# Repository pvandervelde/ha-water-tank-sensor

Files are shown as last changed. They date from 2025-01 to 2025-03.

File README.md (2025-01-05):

# ha-water-tank-sensor

Stores the code and schematics for the system we use to monitor the level in the water tanks on our
property.

Consists of a IoT device that measures the water level in the tank and sends it to the service
using WIFI. The service extracts the data from the message and sends it to a Grafana stack.

* Schema -> KiCad
* PCB -> KiCad (not done)

## The embedded device

### Hardware

* ESP32-C6 DevKit
* Submerged pressure sensor
* BME280 for temperature and humidity
* Light sensitive diode - To check that the enclosure is still sealed
* Solar panel
* Battery (1.3 Ah)
* ADS1115 - To read the analog values from the pressure sensor
* TSR_1-2450 - To regulate the voltage from the battery to the ESP32. Generating 5V for the devkit
* SDLA12TA - Solar charge module
* EC2-3NU - Relay to turn on/off the sensor
* XL6009E1 - DC-DC converter to generate 24V for the pressure sensor
* BS170 - N-channel MOSFET to turn on/off the relay

### Pin assignments

* ESP32-C6 DevKit
  * 5V - TSR_1-2450
  * 3V3 - BME280, ADS1115, Light sensitive diode
  * GND - BME280, ADS1115, Light sensitive diode
  * SDA - BME280, ADS1115,
  * SCL - BME280, ADS1115,
  * GPIO 10 - SDA (ADS1115, BME280)
  * GPIO 11 - SCL (ADS1115, BME280)
  * GPIO 18 - Boost enable (BS170)
* ADS1115
  * GND - ESP32
  * VDD - ESP32
  * SDA - ESP32
  * SCL - ESP32
  * ALERT - Not connected
  * A0 - Light sensitive diode
  * A1 - Pressure sensor
  * A2 - Not connected
  * A3 - Battery sensor
* BME280

### Software

## The service

## Communication

* Message format
* connectivity

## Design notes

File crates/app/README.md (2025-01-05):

# Water tank level - The embedded application

Based on: <https://diyodemag.com/projects/arduino_lorawan_enabled_water_tank_level_monitoring_part_1>
and <https://github.com/ajw2060/LoRaWAN-Tank-Sensor-Project>

Measures the water level in a tank and sends it to the service using WIFI.

Uses the following components:

* ESP32-C6 DevKit
* Submerged pressure sensor
* BME280 for temperature and humidity
* Light sensitive diode - To check that the enclosure is still sealed
* Solar panel
* Battery (1.3 Ah)
* ADS1115 - To read the analog values from the pressure sensor
* TSR_1-2450 - To regulate the voltage from the battery to the ESP32. Generating 5V for the devkit
* SDLA12TA - Solar charge module
* EC2-3NU - Relay to turn on/off the sensor

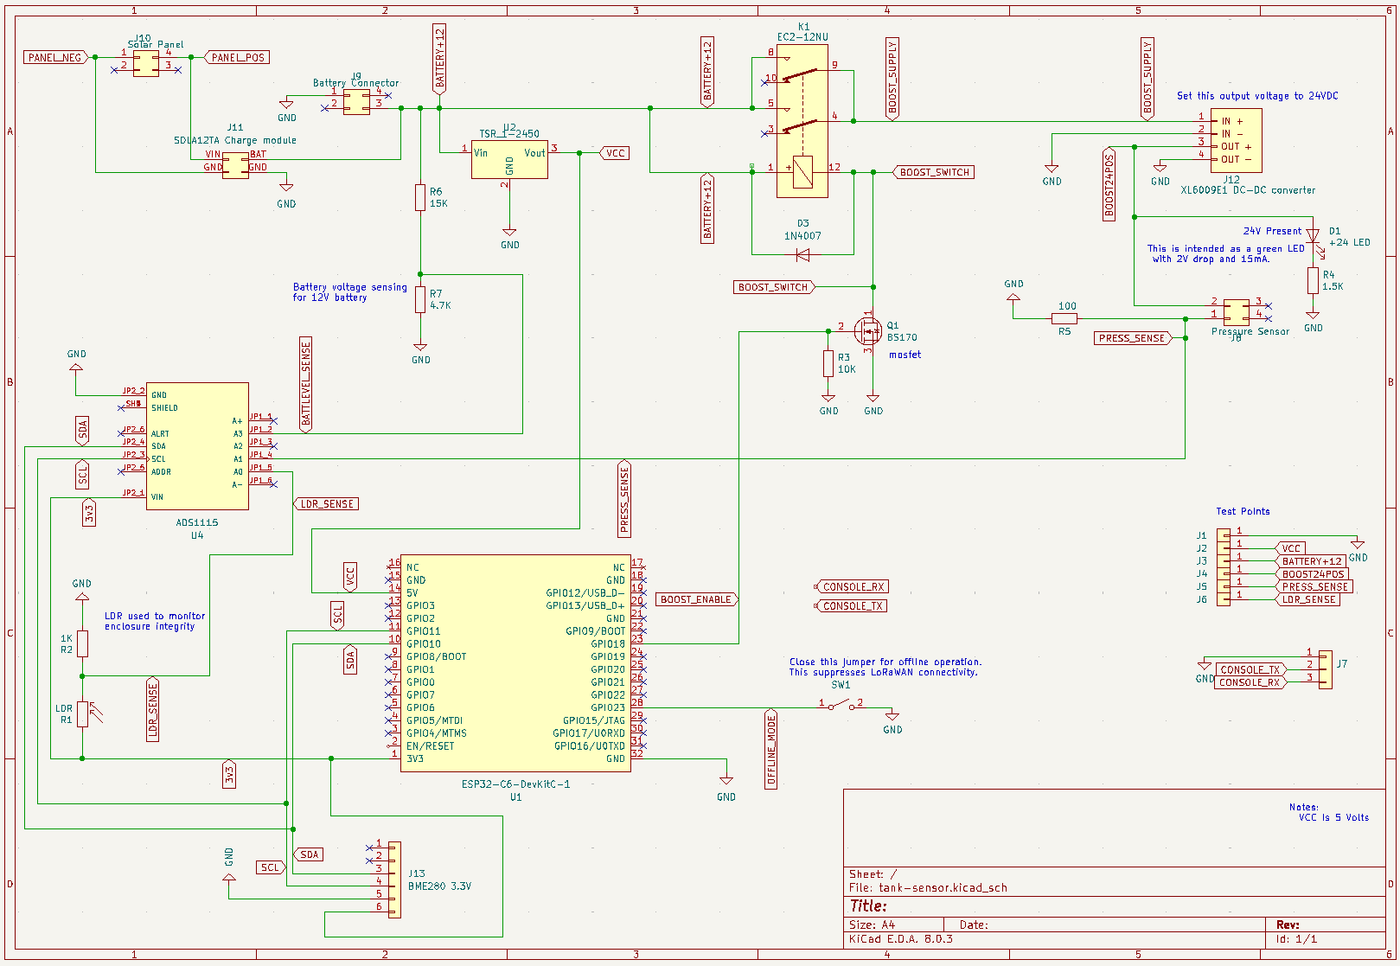
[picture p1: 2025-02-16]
doc/img/schema.png

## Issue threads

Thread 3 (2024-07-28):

Complete schema

pvandervelde, 2024-07-28:
Complete the schema as copied from: https://diyodemag.com/projects/arduino_lorawan_enabled_water_tank_level_monitoring_part_1.

The schema provided has custom components that are not available so we need to create those and wire them up correctly. Also we need to verify that the schema is correct for our components.

pvandervelde, 2024-09-11:
The schema currently is fully laid out. I still need to check the value for the resistors and verify the value for the diode that is used around the boost supply.

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

Closed 2024-12-14.

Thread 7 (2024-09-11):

Get a sensor frame to hold the submerged sensors

pvandervelde, 2024-09-11:
We want to hold the submerged sensors close to the bottom of the tank, but not on the bottom of the tank because the bottom will be covered with random crap.

pvandervelde, 2025-01-05:
Had a cage type thing welded

Closed 2025-01-05.

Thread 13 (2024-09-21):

Create the code to read the sensor

pvandervelde, 2024-09-21:

pvandervelde, 2025-03-01:
Fixed in #33

Closed 2025-03-01.

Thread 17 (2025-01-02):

Determine if we need to provide cooling for the enclosure

pvandervelde, 2025-01-02:
The worry is that the enclosure will become too hot during summer as there is no ventilation. So we may need ventilation slots and possibly a ventilation fan. If we do need extra ventilation then we will also need to ensure that no water can get into the enclosure. And possibly we need to ensure that the humidity doesn't get too high.

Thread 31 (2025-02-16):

Ensure that we synchronise the time at least once every hour

pvandervelde, 2025-02-16:
At the moment we only sychronise the time if we don't already have it stored, i.e. after a full power down. We should however synchronise at least once an hour to keep some form of accuracy.

pvandervelde, 2025-03-01:
This is no longer needed because we don't need the embedded app to know what time it is. The time the metrics were recorded is stored by the service.

Closed 2025-03-01.

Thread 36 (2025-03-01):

Embedded app stops sending data after about an hour

pvandervelde, 2025-03-01:
For some reason after about an hour we stop getting data from the device. At the moment we don't have any logs coming from the device so there is no way of knowing what is happening.

pvandervelde, 2025-03-14:
One potential reason for this might be that in order for the device to go into deep sleep it has to shut the wifi down. If the wifi shutdown doesn't work as expected a call to the sleep function will hang forever

Closed 2025-03-20.

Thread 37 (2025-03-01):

Send device log to the service

pvandervelde, 2025-03-01:
We need to get the log from the device to somewhere safe so that we can find out what is going on when there are issues.

Closed 2025-03-12.

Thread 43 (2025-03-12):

Remove the embassy task sections because they are overkill

pvandervelde, 2025-03-12:
The embedded app code has a number of `embassy_executor::task` sections that allow asynchronous tasks to run. However the workflow for the embedded app doesn't really need a bunch of async tasks, it could very easily run as a serial set of commands, like:

* Set up logger
* Set up wifi
* Collect sensor data
* Send sensor data
* Send logs
* Shutdown

The task approach was originally added because that is what the examples provided. Now that we know better it is clear that we don't need this anymore.

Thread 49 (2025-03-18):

Embedded device fails to disconnect

pvandervelde, 2025-03-18:
In some cases the embedded device does not disconnect from the wifi for an extended period of time. It is certain if this is due to some wifi error or something else.

Potential solutions:
- Detect issues when sending and disconnect
- Detect issues from the service and at least log the issue

Closed 2025-03-20.

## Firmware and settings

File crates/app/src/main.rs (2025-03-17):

// Based on code from here: https://github.com/claudiomattera/esp32c3-embassy/

#![no_std]
#![no_main]

extern crate alloc;

use core::convert::Infallible;

use embassy_sync::blocking_mutex::raw::CriticalSectionRawMutex;
use embassy_sync::channel::Channel;
use embassy_sync::channel::Receiver;
use esp_hal::peripherals::Peripherals;
use esp_hal::peripherals::LPWR;
use esp_hal::ram;
use esp_hal::reset::software_reset;
use esp_hal::time::now;
use esp_hal_embassy::main;
use esp_wifi::wifi::WifiController;
use log::error;
use log::info;

use embassy_executor::Spawner;

use esp_alloc as _;

use esp_hal::clock::CpuClock;
use esp_hal::init as initialize_esp_hal;
use esp_hal::rng::Rng;
use esp_hal::timer::systimer::SystemTimer;
use esp_hal::Config as EspConfig;

use esp_hal_embassy::init as initialize_embassy;

use logging::send_logs_to_server;
use thiserror::Error;

use heapless::String;

use esp_backtrace as _;
use wifi::MonitorTaskResult;

mod board_components;

mod cell;
use self::cell::SyncUnsafeCell;

mod data_recording;
use self::data_recording::send_metrics_to_server;

mod device_meta;

mod logging;
use self::logging::setup_logger as setup_logging;

mod meta;

mod random;
use self::random::RngWrapper;

mod sensor;
use self::sensor::read_sensor_data;
use self::sensor::SensorPeripherals;

mod sensor_data;

mod sleep;
use self::sleep::enter_deep as enter_deep_sleep;

mod timing;
use self::timing::send_timing_data;

mod wifi;
use self::wifi::WifiConnectionError as WifiError;

/// Duration of deep sleep
const DEEP_SLEEP_DURATION_IN_SECONDS: u32 = 30;

/// SSID for WiFi network
const WIFI_SSID: &str = env!("WIFI_SSID");

/// Password for WiFi network
const WIFI_PASSWORD: &str = env!("WIFI_PASSWORD");

/// Size of heap for dynamically-allocated memory
const HEAP_MEMORY_SIZE: usize = 72 * 1024;

/// Stored boot count between deep sleep cycles
///
/// This is a statically allocated variable and it is placed in the RTC Fast
/// memory, which survives deep sleep.
#[ram(rtc_fast)]
static BOOT_COUNT: SyncUnsafeCell<u32> = SyncUnsafeCell::new(0);

static WIFI_MONITOR_RESULT_CHANNEL: Channel<CriticalSectionRawMutex, MonitorTaskResult, 1> =
    Channel::new();

/// An error
#[derive(Debug, Error)]
enum Error {
    /// An impossible error existing only to satisfy the type system
    #[error("An impossible error existing only to satisfy the type system")]
    Impossible {
        #[from]
        source: Infallible,
    },

    #[error("The network was disconnected")]
    NetworkDisconnected,

    /// An error within WiFi operations
    #[error("An error within WiFi operations")]
    Wifi {
        #[from]
        source: WifiError,
    },
}

// Function to check WiFi status. If this function returns an error then we have not been
// able to keep the connection alive even through a number of retries.
async fn check_wifi_status(
    monitor_receiver: Receiver<'static, CriticalSectionRawMutex, MonitorTaskResult, 1>,
) -> Result<(), Error> {
    match monitor_receiver.try_receive() {
        Ok(result) => match result {
            wifi::MonitorTaskResult::Success => Ok(()),
            _ => {
                error!("WiFi monitor task reported failure, entering deep sleep");
                Err(Error::NetworkDisconnected)
            }
        },
        // try_receive returns an error if there's nothing on the channel. In that case either the
        // monitor task hasn't started, hasn't done any work or we have already processed the result
        // in a request prior. Just assume everything is fine for the time being.
        Err(_) => Ok(()),
    }
}

async fn disconnect_wifi_and_put_device_to_sleep(
    lpwr: LPWR,
    wifi_controller: &mut WifiController<'_>,
) -> ! {
    // Ensure WiFi is disconnected properly before device state transition
    let wifi_disconnect_result = wifi::disconnect_from_wifi(wifi_controller).await;
    match wifi_disconnect_result {
        Ok(_) => {
            info!("WiFi disconnected successfully, entering deep sleep");
            enter_deep_sleep(
                lpwr,
                hifitime::Duration::from_seconds(DEEP_SLEEP_DURATION_IN_SECONDS as f64),
            );
        }
        Err(e) => {
            error!("Failed to disconnect WiFi, performing software reset: {e}");
            software_reset();
        }
    }

    // This is unreachable as both deep_sleep and software_reset never return
    unreachable!("Device should have entered deep sleep or reset");
}

fn init_heap() {
    static mut HEAP: core::mem::MaybeUninit<[u8; HEAP_MEMORY_SIZE]> =
        core::mem::MaybeUninit::uninit();

    unsafe {
        esp_alloc::HEAP.add_region(esp_alloc::HeapRegion::new(
            HEAP.as_mut_ptr() as *mut u8,
            HEAP_MEMORY_SIZE,
            esp_alloc::MemoryCapability::Internal.into(),
        ));
    }
}

/// Main task
#[main]
async fn main(spawner: Spawner) {
    let peripherals = initialize_esp_hal({
        let mut config = EspConfig::default();
        config.cpu_clock = CpuClock::max();
        config
    });

    // SAFETY:
    // This is the only place where a mutable reference is taken
    let boot_count: Option<&'static mut _> = unsafe { BOOT_COUNT.get().as_mut() };
    // SAFETY:
    // This is pointing to a valid value
    let boot_count: &'static mut _ = unsafe { boot_count.unwrap_unchecked() };
    info!("Current boot count = {boot_count}");
    *boot_count += 1;

    let logger_result = setup_logging(*boot_count);
    if logger_result.is_err() {
        // Everything is stuffed. Just go back to sleep
        enter_deep_sleep(
            peripherals.LPWR,
            hifitime::Duration::from_seconds(DEEP_SLEEP_DURATION_IN_SECONDS as f64),
        );
    }

    main_fallible(spawner, peripherals, *boot_count).await;
}

/// Main task that can return an error
async fn main_fallible(spawner: Spawner, mut peripherals: Peripherals, boot_count: u32) -> ! {
    init_heap();

    let start_time = now();
    let systimer = SystemTimer::new(peripherals.SYSTIMER);
    initialize_embassy(systimer.alarm0);

    let rng = Rng::new(&mut peripherals.RNG);

    // Connect to WiFi and get network stack
    let ssid_result = String::<32>::try_from(WIFI_SSID);
    let password_result = String::<64>::try_from(WIFI_PASSWORD);

    if ssid_result.is_err() || password_result.is_err() {
        error!("No valid Wifi SSID or password provided");
        enter_deep_sleep(
            peripherals.LPWR,
            hifitime::Duration::from_seconds(DEEP_SLEEP_DURATION_IN_SECONDS as f64),
        );
    }

    let ssid = ssid_result.unwrap();
    let password = password_result.unwrap();

    info!("Connecting to WiFi network");
    let wifi_connect_result = wifi::connect_to_wifi(
        spawner,
        peripherals.TIMG0,
        peripherals.WIFI,
        peripherals.RADIO_CLK,
        rng,
        ssid.clone(),
        password.clone(),
    )
    .await;

    if wifi_connect_result.is_err() {
        error!(
            "Failed to connect to WiFi: {:?}",
            wifi_connect_result.err().unwrap()
        );
        enter_deep_sleep(
            peripherals.LPWR,
            hifitime::Duration::from_seconds(DEEP_SLEEP_DURATION_IN_SECONDS as f64),
        );
    }

    let (mut wifi_controller, stack) = wifi_connect_result.unwrap();

    // Create a channel to receive WiFi monitor task results
    let monitor_sender = WIFI_MONITOR_RESULT_CHANNEL.sender();
    let monitor_receiver = WIFI_MONITOR_RESULT_CHANNEL.receiver();

    // Spawn the WiFi monitoring task
    if let Err(e) = spawner.spawn(wifi::wifi_monitor_task_with_channel(
        // SAFETY: The controller needs to be static for the task. Since we're entering deep sleep
        // after this function, we can safely extend the lifetime
        unsafe {
            core::mem::transmute::<
                &mut esp_wifi::wifi::WifiController<'_>,
                &mut esp_wifi::wifi::WifiController<'_>,
            >(&mut wifi_controller)
        },
        monitor_sender,
    )) {
        error!("Failed to spawn WiFi monitor task: {:?}", e);
        disconnect_wifi_and_put_device_to_sleep(peripherals.LPWR, &mut wifi_controller).await;
    }

    // Get duration for operations
    let current_time = now();
    let wifi_start_time_in_micro_seconds = current_time
        .checked_duration_since(start_time)
        .unwrap()
        .to_micros();

    // Check WiFi status before each major operation
    let mut wifi_status_result = check_wifi_status(monitor_receiver).await;
    if wifi_status_result.is_err() {
        error!("Failed to keep network connection alive.");
        disconnect_wifi_and_put_device_to_sleep(peripherals.LPWR, &mut wifi_controller).await;
    }

    if let Err(e) = send_timing_data(stack, boot_count).await {
        error!("Failed to send timing data: {e:?}");
        disconnect_wifi_and_put_device_to_sleep(peripherals.LPWR, &mut wifi_controller).await;
    }

    wifi_status_result = check_wifi_status(monitor_receiver).await;
    if wifi_status_result.is_err() {
        error!("Failed to keep network connection alive.");
        disconnect_wifi_and_put_device_to_sleep(peripherals.LPWR, &mut wifi_controller).await;
    }

    match send_logs_to_server(stack).await {
        Ok(_) => (),
        Err(e) => {
            error!("Failed to send the logs to the server: {e:?}");
        }
    };

    wifi_status_result = check_wifi_status(monitor_receiver).await;
    if wifi_status_result.is_err() {
        error!("Failed to keep network connection alive.");
        disconnect_wifi_and_put_device_to_sleep(peripherals.LPWR, &mut wifi_controller).await;
    }

    let sensor_read_result = read_sensor_data(SensorPeripherals {
        sda: peripherals.GPIO10,
        scl: peripherals.GPIO11,
        pressure_sensor_enable: peripherals.GPIO18,
        i2c0: peripherals.I2C0,
        rng,
    })
    .await;

    if sensor_read_result.is_err() {
        error!("Failed to read sensor data");
        disconnect_wifi_and_put_device_to_sleep(peripherals.LPWR, &mut wifi_controller).await;
    } else {
        let (bme280_reading, ads1115_reading) = sensor_read_result.unwrap();

        wifi_status_result = check_wifi_status(monitor_receiver).await;
        if wifi_status_result.is_err() {
            error!("Failed to keep network connection alive.");
            disconnect_wifi_and_put_device_to_sleep(peripherals.LPWR, &mut wifi_controller).await;
        }

        let _ = send_metrics_to_server(
            stack,
            bme280_reading,
            ads1115_reading,
            boot_count,
            start_time,
            wifi_start_time_in_micro_seconds,
        )
        .await;
    }

    // Prepare to shut down. Turn off the logger
    info!(
        "Entering deep sleep for {}s",
        DEEP_SLEEP_DURATION_IN_SECONDS,
    );

    wifi_status_result = check_wifi_status(monitor_receiver).await;
    if wifi_status_result.is_err() {
        error!("Failed to keep network connection alive.");
        disconnect_wifi_and_put_device_to_sleep(peripherals.LPWR, &mut wifi_controller).await;
    }

    match send_logs_to_server(stack).await {
        Ok(_) => (),
        Err(e) => {
            error!("Failed to send the logs to the server: {e:?}");
        }
    };

    disconnect_wifi_and_put_device_to_sleep(peripherals.LPWR, &mut wifi_controller).await;
}

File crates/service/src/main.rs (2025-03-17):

// time
use chrono::Utc;

// REST
use axum::{
    extract::{rejection::JsonRejection, Extension, Json, Path, Query, Request, State},
    http::StatusCode,
    response::IntoResponse,
    routing::{get, post},
    Router,
};

use once_cell::sync::Lazy;

// HTTP
use tower_http::trace::TraceLayer;

// JSON
use serde::{Deserialize, Serialize};

// Observability
use opentelemetry::KeyValue;
use opentelemetry::{global, InstrumentationScope};
use opentelemetry::{metrics::Meter, trace::TraceError};
use opentelemetry_appender_tracing::layer::OpenTelemetryTracingBridge;
use opentelemetry_otlp::{LogExporter, MetricExporter, SpanExporter, WithExportConfig};
use opentelemetry_sdk::metrics::{MetricError, PeriodicReader, SdkMeterProvider};
use opentelemetry_sdk::{
    logs::{LogError, LoggerProvider},
    metrics::Temporality,
};
use opentelemetry_sdk::{runtime, trace as sdktrace, Resource};
use tracing::{debug, error, info, instrument};
use tracing_subscriber::layer::SubscriberExt;
use tracing_subscriber::{prelude::*, EnvFilter};

// Error handling
use anyhow::Result;

#[cfg(test)]
#[path = "main_tests.rs"]
mod main_tests;

static RESOURCE: Lazy<Resource> = Lazy::new(|| {
    Resource::new(vec![KeyValue::new(
        opentelemetry_semantic_conventions::resource::SERVICE_NAME,
        "tank-sensor-service",
    )])
});

#[derive(Debug, Deserialize, Serialize, Clone, PartialEq)]
struct SensorData {
    device_id: String,
    firmware_version: String,
    boot_count: u32,
    run_time_in_seconds: f64,
    wifi_start_time_in_seconds: f64,
    temperature_in_celcius: f32,
    humidity_in_percent: f32,
    pressure_in_pascal: f32,
    brightness_in_percent: f32,
    battery_voltage: f32,
    pressure_sensor_voltage: f32,
    tank_level_in_meters: f32,
    tank_temperature_in_celcius: f32,
}

impl SensorData {
    fn validate(&self) -> Result<(), String> {
        if self.boot_count < 1 {
            return Err("The device boot count should at least be 1.".to_string());
        }

        if self.run_time_in_seconds < 0.0 {
            return Err("Run time out of reasonable range (> 0.0)".to_string());
        }

        if self.wifi_start_time_in_seconds < 0.0 {
            return Err("Wifi start time out of reasonable range (> 0.0)".to_string());
        }

        if self.temperature_in_celcius < -50.0 || self.temperature_in_celcius > 100.0 {
            return Err("Temperature out of reasonable range (-50°C to 100°C)".to_string());
        }

        if self.humidity_in_percent < 0.0 || self.humidity_in_percent > 100.0 {
            return Err("Humidity must be between 0% and 100%".to_string());
        }

        if self.pressure_in_pascal < 50.0e3 || self.pressure_in_pascal > 150.0e3 {
            return Err("Pressure out of reasonable range (500-1500 hPa)".to_string());
        }

        if self.brightness_in_percent < 0.0 || self.brightness_in_percent > 100.0 {
            return Err("Enclosure brightness must be bewteen 0% and 100%".to_string());
        }

        if self.battery_voltage < 0.0 || self.battery_voltage > 15.0 {
            return Err("Battery voltage out of reasonable range (0.0V to 15.0V)".to_string());
        }

        if self.pressure_sensor_voltage < 0.0 || self.pressure_sensor_voltage > 32.0 {
            return Err(
                "Pressure sensor voltage out of reasonable range (0.0V to 32.0V)".to_string(),
            );
        }

        if self.tank_level_in_meters < 0.0 || self.tank_level_in_meters > 5.0 {
            return Err("Tank water level out of reasonable range (0.0m to 5.0m)".to_string());
        }

        if self.tank_temperature_in_celcius < -50.0 || self.tank_temperature_in_celcius > 100.0 {
            return Err(
                "Tank water temperature out of reasonable range (-50°C to 100°C)".to_string(),
            );
        }

        Ok(())
    }
}

#[derive(Debug, Serialize, Deserialize)]
struct ApiResponse {
    status: String,
    timestamp: String,
    message: String,
}

impl ApiResponse {
    fn success(message: impl Into<String>) -> Self {
        Self {
            status: "success".to_string(),
            timestamp: Utc::now().to_rfc3339(),
            message: message.into(),
        }
    }

    fn error(message: impl Into<String>) -> Self {
        Self {
            status: "error".to_string(),
            timestamp: Utc::now().to_rfc3339(),
            message: message.into(),
        }
    }
}

#[derive(Debug, Deserialize, Serialize)]
struct LogData {
    device_id: String,
    level: String,
    message: String,
    boot_count: u32,
    timestamp: u64,
}

#[derive(Debug, Deserialize, Serialize)]
struct DeviceTimingData {
    device_id: String,
    boot_count: u32,
    timestamp: u64,
}

#[derive(Debug, Clone)]
struct DeviceTimeMapping {
    boot_count: u32,
    first_tick: u64,
    first_timestamp: chrono::DateTime<chrono::Utc>,
}

#[derive(Clone)]
struct ObservabilityConfig {
    metrics_push_url: String,
    trace_push_url: String,
    logs_push_url: String,
}

#[derive(Clone)]
struct AppState {
    device_time_mappings:
        std::sync::Arc<tokio::sync::RwLock<std::collections::HashMap<String, DeviceTimeMapping>>>,
}

impl AppState {
    fn new() -> Self {
        Self {
            device_time_mappings: std::sync::Arc::new(tokio::sync::RwLock::new(
                std::collections::HashMap::new(),
            )),
        }
    }
}
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

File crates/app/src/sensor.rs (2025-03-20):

// Based on code from here: https://github.com/claudiomattera/esp32c3-embassy/

//! Task for reading sensor value

// ESP32
use esp_hal::gpio::Output;
use esp_hal::gpio::{GpioPin, Level};
use esp_hal::i2c::master::Config as I2cConfig;
use esp_hal::i2c::master::Error as I2cError;
use esp_hal::i2c::master::I2c;
use esp_hal::peripherals::I2C0;
use esp_hal::rng::Rng;
use esp_hal::time::RateExtU32;
use esp_hal::Async;

// Components
use ads1x1x::ic::{Ads1115, Resolution16Bit};
use ads1x1x::TargetAddr;
use ads1x1x::{channel, Ads1x1x};

use bme280_rs::AsyncBme280;
use bme280_rs::Configuration;
use bme280_rs::Oversampling;
use bme280_rs::Sample as Bme280Sample;
use bme280_rs::SensorMode;

use heapless::Vec;

use libm::fabsf;

use log::debug;
use log::error;
use log::info;
use log::warn;

use embassy_time::Timer;
use embassy_time::{Delay, Duration};

use nb::block;
use uom::si::electric_potential::volt;
use uom::si::f32::ElectricPotential as Voltage;
use uom::si::f32::Length;
use uom::si::f32::Pressure;
use uom::si::f32::Ratio;
use uom::si::f32::ThermodynamicTemperature as Temperature;
use uom::si::length::meter;
use uom::si::pressure::hectopascal;
use uom::si::ratio::percent;
use uom::si::thermodynamic_temperature::degree_celsius;

use thiserror::Error;

use crate::board_components::{
    MPU_OUTPUT_VOLTAGE, PRESSURE_SENSOR_MAXIMUM_HEIGHT,
    PRESSURE_SENSOR_OUTPUT_RESISTOR_AFTER_PROBE, VOLTAGE_DIVIDER_BATTERY_RESISTOR_AFTER_PROBE,
    VOLTAGE_DIVIDER_BATTERY_RESISTOR_BEFORE_PROBE,
    VOLTAGE_DIVIDER_PRESSURE_SENSOR_RESISTOR_AFTER_PROBE,
    VOLTAGE_DIVIDER_PRESSURE_SENSOR_RESISTOR_BEFORE_PROBE,
};
use crate::sensor_data::Ads1115Data;
use crate::sensor_data::Bme280Data;
use crate::sensor_data::Error as DomainError;
use crate::sensor_data::NUMBER_OF_SAMPLES;
use crate::sensor_data::TIME_BETWEEN_SAMPLES_IN_SECONDS;

type Adc<'a> = Ads1x1x<I2c<'a, Async>, Ads1115, Resolution16Bit, ads1x1x::mode::OneShot>;

/// Interval to wait for sensor warmup, 10 milliseconds (aka 0.01 seconds)
const WARMUP_INTERVAL_IN_MILLISECONDS: f64 = 10.0;

// Interval to wait between checking if the pressure sensor voltage is stable
const PRESSURE_SENSOR_VOLTAGE_STABILIZATION_CHECK_INTERVAL_IN_SECONDS: f64 = 0.010;

// The voltage for the pressure sensor
const EXPECTED_PRESSURE_SENSOR_VOLTAGE: f32 = 24.0;

/// Error within sensor sampling
#[derive(Debug, Error)]
pub enum SensorError {
    /// Error from domain
    #[error("There was an error from the domain")]
    Domain(DomainError),

    /// Error from I²C bus
    #[error("An error has occurred with the I2c bus.")]
    I2c(#[expect(unused, reason = "Never read directly")] I2cError),

    #[error("The ADC voltage range could not be set.")]
    FailedToSetAdcRange,

    #[error("The pressure sensor voltage is not stable.")]
    PressureSensorVoltageNotStable,

    #[error("Failed to initialize I2C")]
    I2cInitializationFailed,
}

impl From<DomainError> for SensorError {
    fn from(error: DomainError) -> Self {
        Self::Domain(error)
    }
}

impl From<I2cError> for SensorError {
    fn from(error: I2cError) -> Self {
        Self::I2c(error)
    }
}

/// Peripherals used by the sensor
pub struct SensorPeripherals {
    /// I²C SDA pin
    pub sda: GpioPin<10>,
    /// I²C SCL pin
    pub scl: GpioPin<11>,

    // The pin that enables or disables the pressure sensor
    pub pressure_sensor_enable: GpioPin<18>,

    /// I²C interface
    pub i2c0: I2C0,

    /// Random number generator
    pub rng: Rng,
}

async fn calculate_ads1115_voltage(measured_value: i16) -> f32 {
    // Convert to voltage (ADS1115 is 16-bit, ±2.048V full scale)
    (measured_value as f32 * 2.048) / 32768.0
}

fn calculate_input_voltage_for_voltage_divider(
    output_voltage: f32,
    resistor_before_probe: f32,
    resistor_after_probe: f32,
) -> f32 {
    output_voltage * (resistor_before_probe + resistor_after_probe) / resistor_after_probe
}

fn calculate_water_height_from_pressure_sensor_voltage(
    voltage: f32,
    resistor: f32,
    sensor_maximum_height: f32,
) -> f32 {
    // Constants for 4-20mA sensor
    const MIN_CURRENT: f32 = 0.004; // 4mA
    const MAX_CURRENT: f32 = 0.020; // 20mA

    // Calculate minimum voltage (at 4mA)
    let min_voltage = MIN_CURRENT * resistor;

    // Calculate maximum voltage (at 20mA)
    let max_voltage = MAX_CURRENT * resistor;
    let voltage_range = max_voltage - min_voltage;

    // Calculate height
    (voltage - min_voltage) * sensor_maximum_height / voltage_range
}

async fn initialize_bme280(
    bme280: &mut AsyncBme280<I2c<'static, Async>, Delay>,
) -> Result<(), I2cError> {
    info!("Initializing the BME280");
    bme280.init().await?;

    info!("Configuring the BME280");
    bme280
        .set_sampling_configuration(
            Configuration::default()
                .with_temperature_oversampling(Oversampling::Oversample1)
                .with_pressure_oversampling(Oversampling::Oversample1)
                .with_humidity_oversampling(Oversampling::Oversample1)
                .with_sensor_mode(SensorMode::Normal),
        )
        .await?;
    Ok(())
}
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

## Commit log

2024-07-30 chore: Add the GHA workflow to send issues and PRs to the Kanban board
2024-07-30 chore(deps): pin actions/add-to-project action to 244f685
2024-09-09 feat: Ignore the KiCad backup files
2024-09-09 feat: Adding the KiCad files
    [tank-sensor.kicad_pcb, tank-sensor.kicad_sch]
2024-09-09 chore: Ignore the KiCad autosave
2024-09-09 feat: Update component names
    [tank-sensor.kicad_sch]
2024-09-09 feat: More updates to schematics
    [tank-sensor.kicad_sch]
2024-09-11 feat:Connected all the parts in the schematic
    Almost complete, need to verify numbers for resistors
    and diodes
    #3
    [tank-sensor.kicad_sch]
2024-10-27 Just in case
    [tank-sensor.kicad_pcb, tank-sensor.kicad_sch]
2025-01-05 chore(deps): pin dependencies
2025-01-11 Re-doing the whole embedded app to use embassy
    Taken this from https://github.com/claudiomattera/esp32c3-embassy/
    because I can't get it to work without a good
    example. Rewriting parts to fit my purpose.
2025-02-07 Store the version number inside the device code
2025-02-16 Add the ability to measure the pressure sensor voltage
    [tank-sensor.kicad_sch]
2025-02-16 Track the time the device takes from wake up to sending the metrics
2025-02-16 Start working on recording the pressure sensor data
2025-02-20 Add reading the ADS1115 analog-digital converter
    This also requires making changes to the different voltage
    divider resistors.
    [tank-sensor.kicad_sch]
2025-02-23 Removed the on/off button
    [tank-sensor.kicad_sch]
2025-02-26 Store the ESP32 kit output voltage
2025-02-26 Don't store the time on the device
    We'll get that in the app
2025-02-26 Update the schema
    [tank-sensor.kicad_pcb]
2025-03-02 Working on a logger that sends the logs to a server
    So that we can even see logs after a device sleep-wake cycle
2025-03-10 Add more sockets so we can send both metrics and logs at the same time
2025-03-12 Fixing sending the logs to the server
    [main.rs, sensor.rs]
2025-03-17 Properly calculate the light intensity in the enclosure
2025-03-17 Trying to make the wifi behave better.
    Changes:
    - Better wifi monitoring
    - Better wifi disconnection so we can sleep the device
    - Set the wifi power save mode to none (based on a reported issue in the esp_hal)
    [main.rs]
2025-03-19 Temporarily set the maximum pressure sensor voltage variance to 1V for testing
